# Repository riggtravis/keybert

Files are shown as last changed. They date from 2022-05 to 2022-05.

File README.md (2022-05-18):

# Keybert
Copyright Travis W Rigg

This source describes Open Hardware and is licensed under the CERN-OHL-P
v2

You may redistribute and modify this documentation and make products
using it under the terms of the CERN-OHL-P v2 (https:/cern.ch/cern-ohl).
This documentation is distributed WITHOUT ANY EXPRESS OR IMPLIED
WARRANTY, INCLUDING OF MERCHANTABILITY, SATISFACTORY QUALITY
AND FITNESS FOR A PARTICULAR PURPOSE. Please see the CERN-OHL-P v2
for applicable conditions

## The keeb!
Keybert is an ortholinear split keyboard that is intended to be as inexpensive
as possible when built by ordering everything from scratch (including ordering
the PCBs from a PCB vendor that does custom orders). Keybert is also very basic.
The idea behind that was to keep things as simple as possible for the target
audience. Someday in the future, there may be a more feature rich version of
Keybert with all of the fancy things that make "endgame" keyboards "endgame."
But for now, you can get the full fat version of Keybert for not all that much
money (in the world of custom mechanical keyboards) and without needing to be a
wizard at soldering.

With all of that in mind, there are also some other decisions that have been
made to make Keybert a better keyboard for this target audience. Specifically,
there are absolutely no components with overlapping footprints like what you'd
see on some of the keyboards that Keybert was inspired by (in particular the
Let's Split by wootapoot).

An overall listing of features reads as follows:

1. A PCB that can also act as a bottom caseplate
2. Reversible PCB for cost savings when ordering boards
3. All diodes set outside of key matrix
4. Pro Micro set outside of key matrix
5. I2C (I still have no idea what this actually wins you, but it costs all of 2
   resisters so why exclude it from the schematic!?)
6. PCB designed with tenting in mind

## The Roadmap
There are some milestones that Keybert needs to acheive, as well as some pie in
the sky type dreams that might never be acheived, but hey, they'd be nice

Milestones:
1. ~~Compile all CERN OSH recommended documents (gerbers and PDFs)~~
2. ~~Simplify PCB using [the aisler PCB design rules](https://aisler.community/t/pcb-design-rules/41)~~
3. Try to increase minimal drill size
4. Design switch plate
5. Perform basic cost estimate
6. Identify and resolve value shortcomings
7. Order all parts
8. Test build difficulty
9. Identify issues with prototype
10. User acceptance testing
11. Acheive inner peace, never to look at the mechanical keyboard community ever
   again, thus finally escaping the endless hamster wheel that is... "endgame"

Unreasonable dreams:
* Make use of all pins on the Elite C
* Alternative version using BlackPill microcontroller
* Alps compatibility
* Kailh Choc version
* 3D printed case CAD models
* A group buy (to bring prices down further than their already low target)
* Regular commercial availability (for even cheaper keyboards)

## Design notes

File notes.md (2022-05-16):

# Grandiceps (blackpill based keyboard) notes
## Pin connections
columns:
1. col0 -> B0
2. col1 -> A7
3. col2 -> A3
4. col3 -> A5
5. col4 -> A4
6. col5 -> A2

rows:
1. row0 -> B12
2. row1 -> A6
3. row2 -> B13
4. row3 -> B9
5. row4 -> B8

# Ergodone (pro micro based)
## Pin connections
rows:
1. row1 -> PB1
2. row0 -> PB2
3. row5 -> PF4
4. row4 -> PF5
5. row3 -> PF6
6. row2 -> PF7

columns:
1. col13 -> PB4
2. col10 -> PC6
3. col8 -> PD1
4. col7 -> PD3
5. col9 -> PD4
6. col11 -> PD7
7. col12 -> PE6

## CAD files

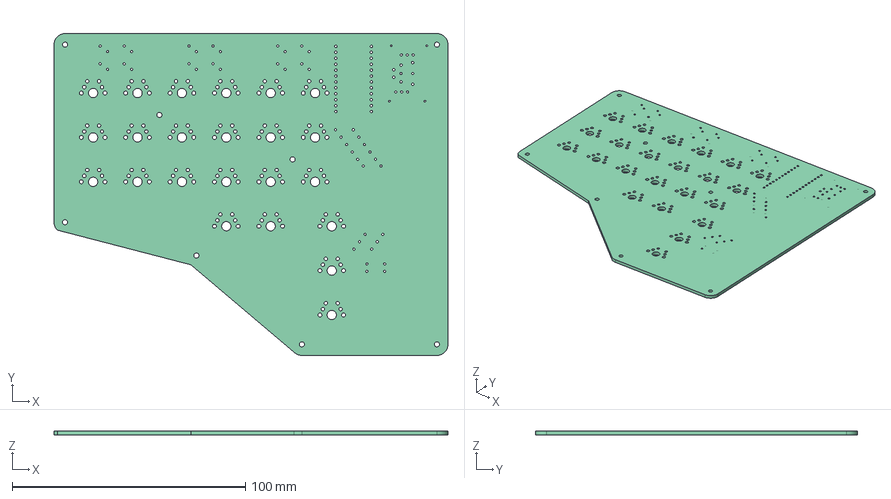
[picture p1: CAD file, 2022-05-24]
keybert/parametric.model.FCStd
169.1 x 138.1 x 1.60 mm

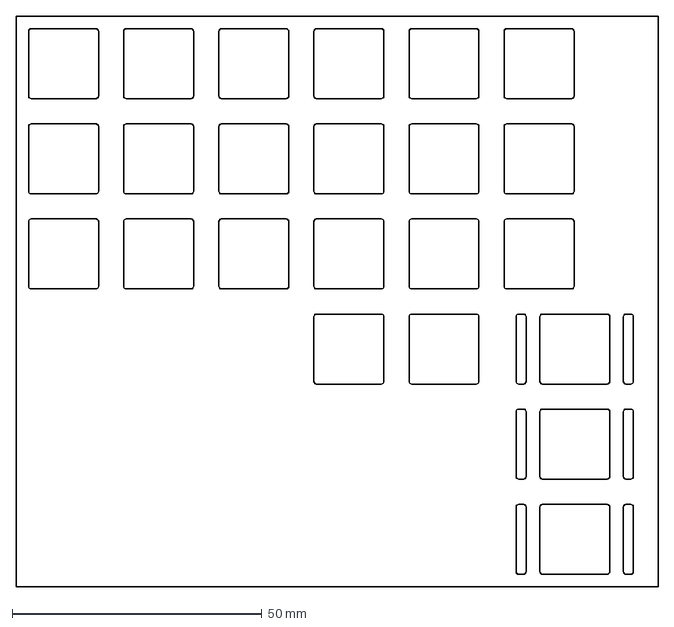
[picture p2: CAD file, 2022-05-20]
keybert/switch.plate.dxf
128.6 x 114.3 mm

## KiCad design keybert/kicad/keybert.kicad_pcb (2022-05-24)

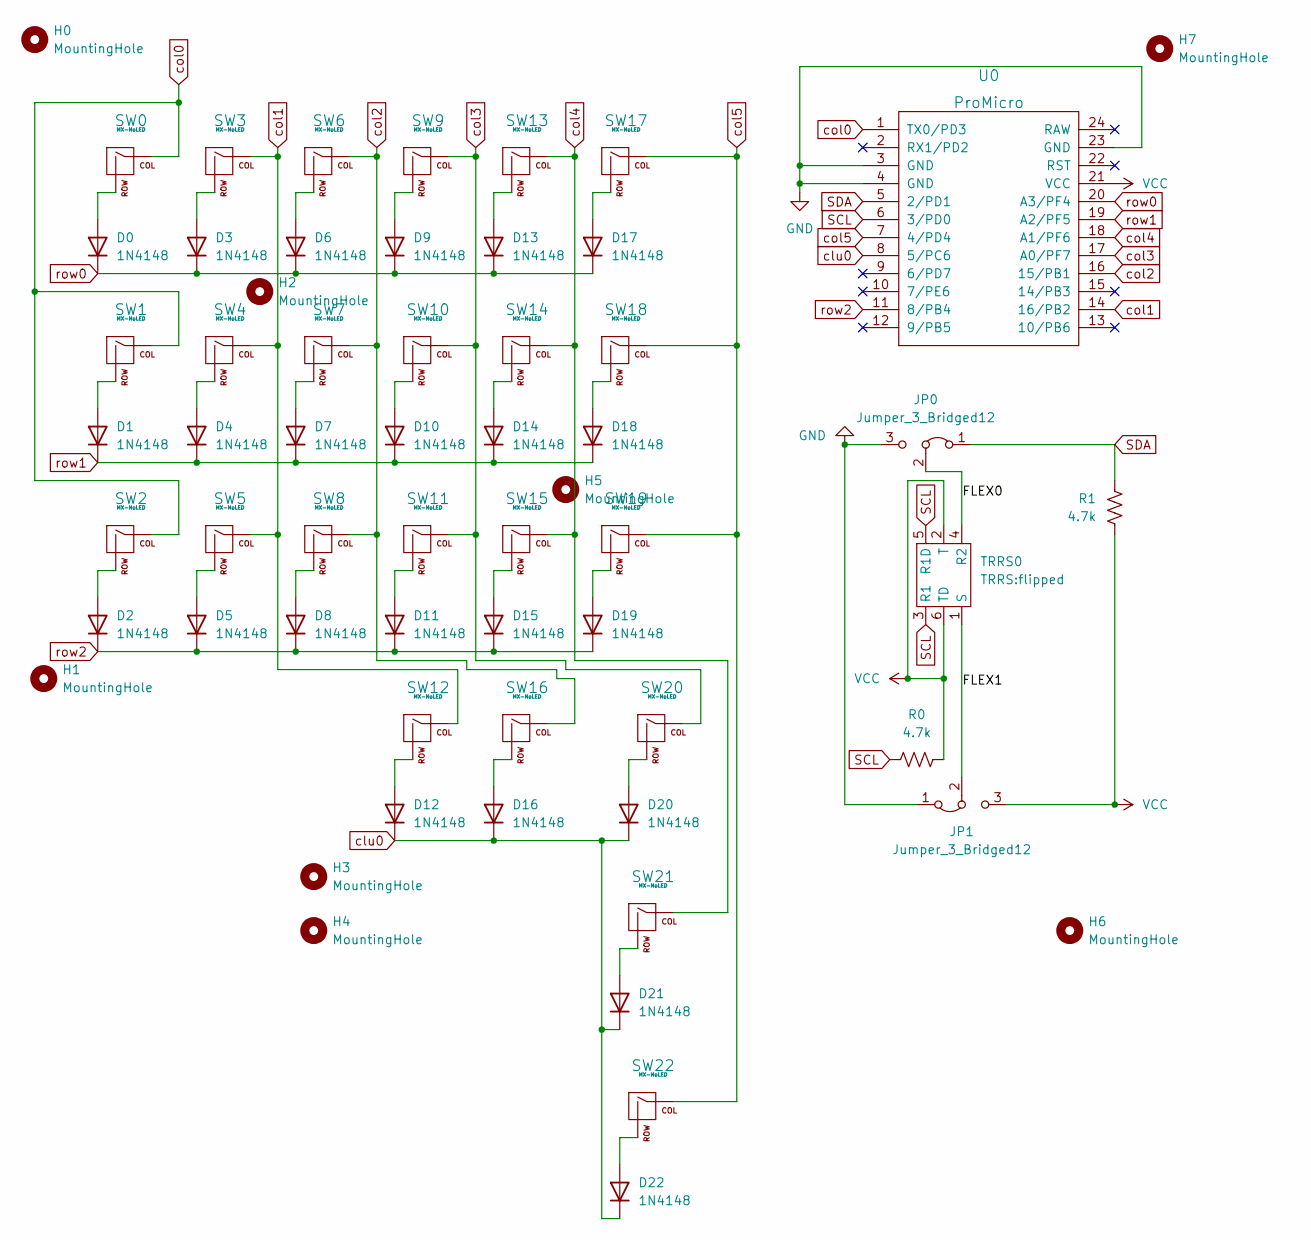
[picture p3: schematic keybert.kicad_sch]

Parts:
D0, D1, D2, D3, D4, D5, D6, D7, D8, D9, D10, D11, D12, D13, D14, D15, D16, D17, D18, D19, D20, D21, D22: 1N4148; Diode
H0, H1, H2, H3, H4, H5, H6, H7: MountingHole
JP0, JP1: Jumper_3_Bridged12; PinHeader_1x03_P2.54mm_Vertical
R0, R1: 4.7k; R_Axial_DIN0207_L6.3mm_D2.5mm_P15.24mm_Horizontal
SW0, SW1, SW2, SW3, SW4, SW5, SW6, SW7, SW8, SW9, SW10, SW11, SW12, SW13, SW14, SW15, SW16, SW17, SW18, SW19, SW20, SW21, SW22: MX-NoLED; SW_MX_reversible
TRRS0: TRRS:flipped; TRRS_Jack
U0: ProMicro; ArduinoProMicro

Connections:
/FLEX0: JP0.2 (C), TRRS0.4 (R2)
/FLEX1: JP1.2 (C), TRRS0.1 (S)
GND: JP0.3 (B), JP1.1 (A), U0.3 (GND), U0.4 (GND), U0.23 (GND)
unnamed: D0.2 (A), SW0.2 (ROW)
unnamed: D1.2 (A), SW1.2 (ROW)
unnamed: D2.2 (A), SW2.2 (ROW)
unnamed: D3.2 (A), SW3.2 (ROW)
unnamed: D4.2 (A), SW4.2 (ROW)
unnamed: D5.2 (A), SW5.2 (ROW)
unnamed: D6.2 (A), SW6.2 (ROW)
unnamed: D7.2 (A), SW7.2 (ROW)
unnamed: D8.2 (A), SW8.2 (ROW)
unnamed: D9.2 (A), SW9.2 (ROW)
unnamed: D10.2 (A), SW10.2 (ROW)
unnamed: D11.2 (A), SW11.2 (ROW)
unnamed: D12.2 (A), SW12.2 (ROW)
unnamed: D13.2 (A), SW13.2 (ROW)
unnamed: D14.2 (A), SW14.2 (ROW)
unnamed: D15.2 (A), SW15.2 (ROW)
unnamed: D16.2 (A), SW16.2 (ROW)
unnamed: D17.2 (A), SW17.2 (ROW)
unnamed: D18.2 (A), SW18.2 (ROW)
unnamed: D19.2 (A), SW19.2 (ROW)
unnamed: D20.2 (A), SW20.2 (ROW)
unnamed: D21.2 (A), SW21.2 (ROW)
unnamed: D22.2 (A), SW22.2 (ROW)
SCL: R0.2, TRRS0.3 (R1), TRRS0.5 (R1D), U0.6 (3/PD0)
SDA: JP0.1 (A), R1.1, U0.5 (2/PD1)
VCC: JP1.3 (B), R0.1, R1.2, TRRS0.2 (T), TRRS0.6 (TD), U0.21 (VCC)
clu0: D12.1 (K), D16.1 (K), D20.1 (K), D21.1 (K), D22.1 (K), U0.8 (5/PC6)
col0: SW0.1 (COL), SW1.1 (COL), SW2.1 (COL), U0.1 (TX0/PD3)
col1: SW3.1 (COL), SW4.1 (COL), SW5.1 (COL), SW12.1 (COL), U0.14 (16/PB2)
col2: SW6.1 (COL), SW7.1 (COL), SW8.1 (COL), SW16.1 (COL), U0.16 (15/PB1)
col3: SW9.1 (COL), SW10.1 (COL), SW11.1 (COL), SW20.1 (COL), U0.17 (A0/PF7)
col4: SW13.1 (COL), SW14.1 (COL), SW15.1 (COL), SW21.1 (COL), U0.18 (A1/PF6)
col5: SW17.1 (COL), SW18.1 (COL), SW19.1 (COL), SW22.1 (COL), U0.7 (4/PD4)
row0: D0.1 (K), D3.1 (K), D6.1 (K), D9.1 (K), D13.1 (K), D17.1 (K), U0.20 (A3/PF4)
row1: D1.1 (K), D4.1 (K), D7.1 (K), D10.1 (K), D14.1 (K), D18.1 (K), U0.19 (A2/PF5)
row2: D2.1 (K), D5.1 (K), D8.1 (K), D11.1 (K), D15.1 (K), D19.1 (K), U0.11 (8/PB4)

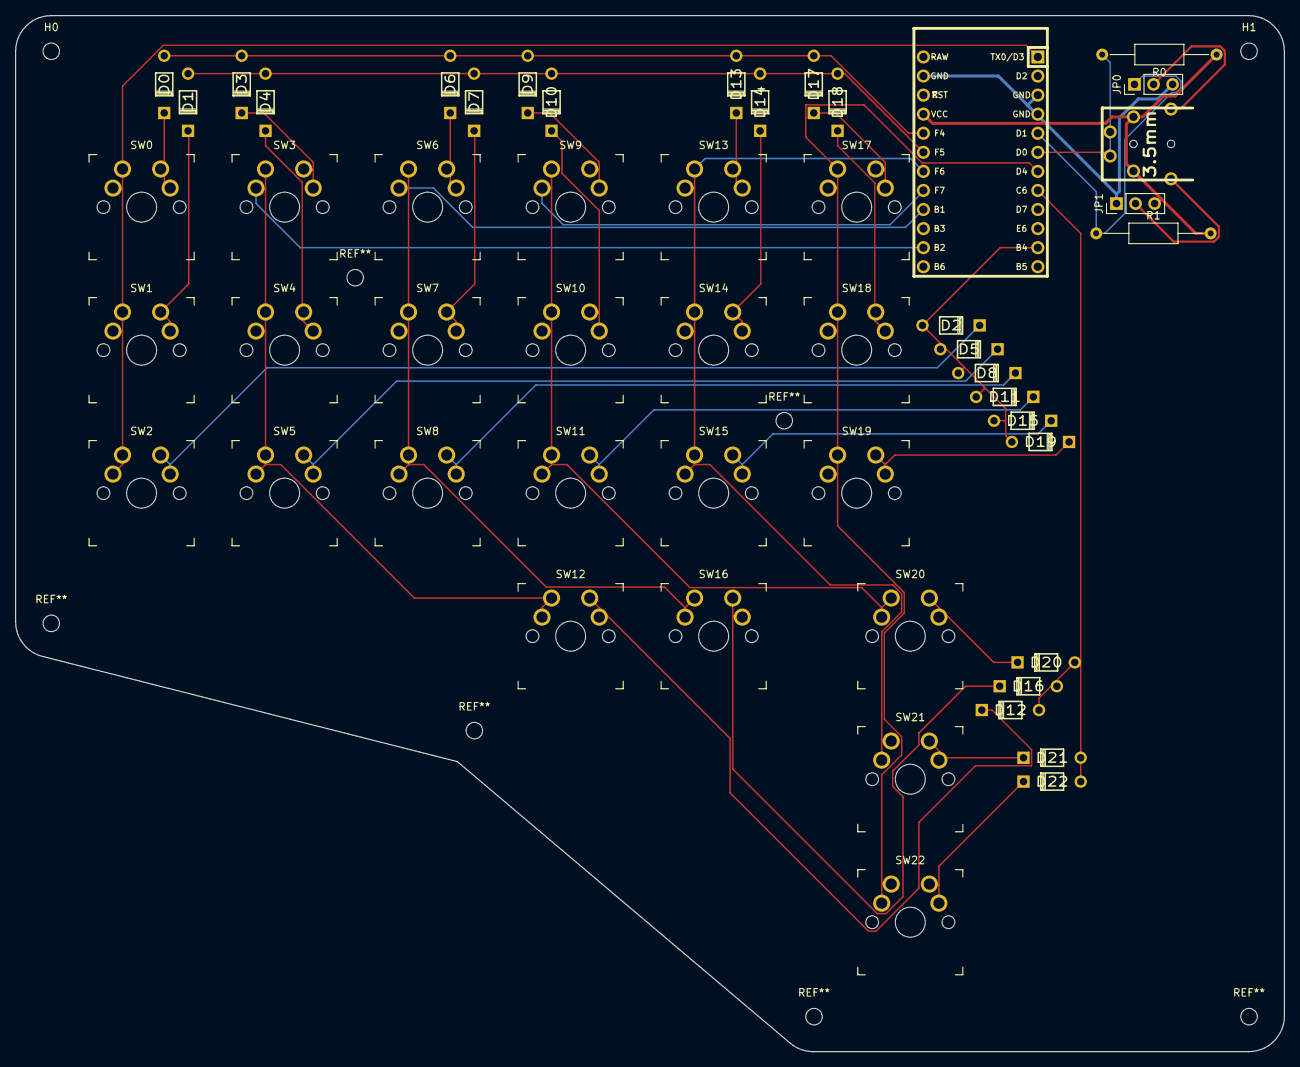
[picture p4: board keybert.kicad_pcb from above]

Board: 2 copper layers, 169.0 x 138.0 mm, 54 parts (1 on the bottom side), 39 nets.

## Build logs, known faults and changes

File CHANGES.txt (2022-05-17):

5/16/2022: Finalized initial design and added initial documentation

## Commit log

2022-05-16 chore: initialize repo with first iteration of kb
    I have reached a point where I think it's simply time to share this
    keyboard with the world and start making the next steps towards
    building it in physical space. It has everything it needs to at
    least convey the ideas I tried to put into it to make it special
    [keybert.kicad_pcb, keybert.kicad_sch]
2022-05-17 chore: add yet more to the start of this repo
    Before this is ready to be initially presented to the world, all of
    the licensing should be fully documented and complied with
    fix: typos in the readme
    chore: add more license information, fix warranty
    This should now be reflective of all of the licensing information I
    want included directly within the specification files as well as
    CERN OSH recommended header in the one place it can go: the README
    [keybert.kicad_pcb, keybert.kicad_sch]
2022-05-17 feat: enforced good board geometry using FreeCAD
    Parametric modeling is a wonderful thing and I'm unclear on why
    KiCAD doesn't have it. Oh well, it is what is is. Using the
    dimensions I obtained from the wonderful experience of performing
    my parametric modeling adjustments, I finally had all of the
    information I needed to get pricing for the PCBs as they are
    currently designed. The results were not good. Currently,
    [Aisler](https://aisler.community/t/pcb-design-rules/41) rates the
    design as complex. This fails to meet the mission goal of Keybert
    in a couple of ways.
    Firstly, a complex PCB is an expensive PCB and an expensive PCB is
    not beginner friendly. Secondly, a complex PCB is a harder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
    [keybert-B_Cu.gbr, keybert-B_Mask.gbr, keybert-B_Silkscreen.gbr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]
2022-05-18 fix: new revision to reduce costs
    Having followed the
    [Aisler design rules](https://aisler.community/t/pcb-design-rules/41)
    I think this new design should be cheaper
    [keybert.kicad_pcb, keybert.kicad_sch]
2022-05-18 fix: No longer incurring complexity fee
    After a lot of work, the PCB itself should now be viable for ordering.
    At time of completion of that work, the PCB is $30 to be produced in the
    United states in a batch of 3 or $22 to be produced in China in a batch
    of 5. Arguably, that batch of five is more in line with the vision for
    Keybert, however, I would forsee myself preferring the American PCB
    manufacturer for my own boards given overall sociopolitical
    circumstances in the world. I have decided that Keybert will exist
    purely in the cheapest possible way with no guidance on how ethical or
    unethical it is to engage with various entities. There likely will need
    to be documentation somewhere stati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
    [keybert.kicad_pcb, keybert.kicad_sch]
2022-05-20 fix: redid PCB due to switch spacing issue
    The spacing of the switches was all wrong I discovered upon loading up
    the switch plate into FreeCAD. I've redone the basic arrangement of all
    electronic parts, but the parts all need, once more to be reconnected.
    I also simplified the schematic slightly. I don't like crossed wires
    even though the ones that do connect are pretty clear thanks to their
    green nodes
    [keybert.kicad_pcb, keybert.kicad_sch, parametric.model.FCStd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]
2022-05-24 feat: remade parametric model of switch plate
    I'm going to have a friend help me get it sorted out why the parameters
    are coming out so under constrained
    [keybert.kicad_pcb, keybert.kicad_sch, parametric.model.FCStd]

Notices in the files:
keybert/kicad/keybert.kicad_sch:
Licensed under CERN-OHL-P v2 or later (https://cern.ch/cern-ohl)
